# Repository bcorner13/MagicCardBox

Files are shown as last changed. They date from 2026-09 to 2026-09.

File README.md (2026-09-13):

# MagicCardBox

A parametric hinged-lid storage box for Magic: The Gathering cards, modeled in FreeCAD 1.1.

Two printed parts, no fasteners. The lid is a single piece that carries the rear wall and
pivots on hinge tabs engaging sockets in the box side walls, so the whole back of the box
folds open.

| | |
|---|---|
| Outer envelope | 97 × 69 × 67 mm (`Width` × `Depth` × `Height`) |
| Wall | 2.0 mm nominal, 6.0 mm at the hinged side walls |
| Parts | Box tub + lid (with integral rear wall) |
| Target | Creality K2 Plus — PLA for test, ASA for production |

## Layout

```
MagicCardBox.FCStd        box tub, hinge sockets
Lid.FCStd                 lid top plate + rear wall + hinge tabs (2 bodies, 1 Part)
MagicCardAssembly.FCStd   assembly with a solved Revolute joint
Params.FCStd              VarSet — every parametric variable lives here
3mf/  stl/                tracked print deliverables
gcode/                    slicer output (gitignored, regenerable)
images/                   renders and screenshots
macros/                   project .FCMacro files — all model changes go in as macros
scripts/                  audit_parametric.py
```

## Working on this model

Read `CLAUDE.md` first — it documents the assembly architecture and this project's
parametric debt. `plan.md` has the literal-to-Param mapping for the outstanding work.

Inspect and edit the `.FCStd` files through the FreeCAD MCP bridge only; a PreToolUse hook
in `.claude/settings.json` blocks shell access to them.

Before committing any model change:

```bash
python3 scripts/audit_parametric.py
```

Baseline at bootstrap (2026-09-13) is **19 issues** — all unbound dimensional literals in
the hinge geometry. Target is zero.

## Status

Geometry is ~95% complete and recomputes clean; every body is a single valid solid. Not yet
printed. Remaining work is parametric cleanup (see `plan.md`), then a PLA test print to tune
the hinge clearances.

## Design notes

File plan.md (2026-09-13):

# Plan — MagicCardBox

**Status:** geometry was built manually before this project was bootstrapped. This plan
documents the as-built model and the remaining work to bring it into compliance with
`PROJECT_BOOTSTRAP.md` / `CAD_STANDARDS.md`.

Last verified against the live model via the FreeCAD MCP bridge: **2026-09-13**
(FreeCAD 1.1.3, all four documents open and unmodified).

---

## PARAMETERS

Current `Params.FCStd` → `VarSet` contents (verified live, 5 variables):

| Name | Type | Default | Drives |
|---|---|---|---|
| `Width` | `App::PropertyLength` | 97.0 mm | Box X extent; lid X extent; hinge sketch offset (`Width / 2`) |
| `Depth` | `App::PropertyLength` | 69.0 mm | Box Y extent; lid Y extent (`Depth + WallThickness`) |
| `Height` | `App::PropertyLength` | 67.0 mm | `Pad.Length` (box body); `LidPlane` datum Z offset |
| `WallThickness` | `App::PropertyLength` | 2.0 mm | Lid `Pad.Length`, `RearWall` `Pad001.Length`, front/back wall pocket offset |
| `SideWallThickness` | `App::PropertyLength` | 6.0 mm | `Pocket002.Length` (`Width − SideWallThickness * 2`) |

### Parameters that MUST be added (currently literals in the model)

These are the 19 audit violations. Each literal below needs a VarSet variable and an
expression binding — one knob, one concern (global rule #5), and clearances decoupled per
mating interface (global rule #4).

| Proposed Param | Type | Value today | Replaces |
|---|---|---|---|
| `HingeTabRadius` | Length | 10.0 mm | `MagicCardBox/Sketch001.Constraints[0]` (Radius), `Lid/Sketch002.Constraints[1]` (Radius) |
| `HingePinDia` | Length | 6.0 mm | `MagicCardBox/Sketch001.Constraints[12]`, `MagicCardBox/Sketch002.Constraints[3]` (Diameter) |
| `HingePinClearance` | Length | **absent** | new — per-side clearance between lid pin hole and box boss. Today all three Ø6 features are the *same* literal, i.e. a zero-clearance interference fit. `Lid/Sketch003.Constraints[0]` becomes `HingePinDia + HingePinClearance * 2`. |
| `HingeAxisInset` | Length | 5.0 mm | `MagicCardBox/Sketch001.Constraints[1]` and `[15]`, `MagicCardBox/Sketch002.Constraints[0]` and `[1]`, `Lid/Sketch002.Constraints[9]`/`[10]`, `Lid/Sketch003.Constraints[3]`/`[7]` — the hinge-axis offset from the rear/bottom edges |
| `HingeTabThickness` | Length | 5.0 mm | `Lid/Pad002.Length` (HingeTab) |
| `HingeSocketDepth` | Length | 5.0 mm | `MagicCardBox/Pocket.Length` |
| `HingeTabClearance` | Length | **absent** | new — per-side clearance between the lid hinge tab and its socket in the box side wall. `Pocket.Length` becomes `HingeTabThickness + HingeTabClearance`. |
| `EdgeFilletRadius` | Length | 1.0 mm | `Lid/Fillet.Radius` |
| *(reuse `WallThickness`)* | — | 2.0 mm | `MagicCardBox/Sketch003.Constraints[9]` and `[10]`, `MagicCardBox/Pocket001.Length` — **only if** these genuinely express wall thickness. Verify before binding; if they express something else, give them their own Param. |

> `HingeAxisInset` is listed as a single knob because every site currently holds the same
> 5.0 mm value **and** they describe the same physical thing (where the pivot sits relative
> to the rear/bottom corner). Confirm that reading against the geometry before binding —
> "variables that just happen to have the same current value are still different concepts."

---

## FEATURE TREE (as built)

### `Params.FCStd`
- `VarSet` (`App::VarSet`) — 5 variables above. No other objects.

### `MagicCardBox.FCStd` — the box body (27 objects)
1. `Part` (`Box001`, App::Part) — container
2. `Body` (`Box`, PartDesign::Body)
3. `Sketch` on `XY_Plane` — outer footprint rectangle. Bound: `Constraints[9] → Width`, `Constraints[10] → Depth`. Fully constrained.
4. `Pad` — `Length → Height`
5. `Sketch001` (`HingProfile`) on `YZ_Plane`, `AttachmentOffset.Base.z → Width / 2` — hinge socket profile on the side wall. **4 unbound literals.**
6. `Pocket` — hinge socket cut. **`Length = 5.0` unbound.**
7. `Sketch002` on `YZ_Plane`, `AttachmentOffset.Base.z → Width / 2` — hinge pin/boss circle. **3 unbound literals.**
8. `Pocket001` — **`Length = 2.0` unbound.**
9. `Mirrored` — mirrors the hinge features to the opposite side wall
10. `Sketch003` on `YZ_Plane` — interior cavity profile. `Constraints[8] → WallThickness`; **`[9]` and `[10]` unbound.**
11. `Pocket002` — `Length → Width − SideWallThickness * 2` (hollows the interior)

### `Lid.FCStd` — the lid + integral rear wall (42 objects)
1. `Part` (`Lid`, App::Part) — container holding both bodies
2. `Body` (`Lid001`) — the top plate
   - `DatumPlane` (`LidPlane`) on `XY_Plane001`, `AttachmentOffset.Base.z → Height`
   - `Sketch` (`LidSketch`) — `Constraints[8] → Width`, `[9] → Depth + WallThickness`, `[10] → Depth / 2`. Fully constrained.
   - `Pad` — `Length → WallThickness`
3. `Body001` (`LidBack`) — the rear wall that swings with the lid
   - `Sketch001`, `AttachmentOffset.Base.z → -Depth`; `Constraints[8] → Width`, `[9] → Height`
   - `Pad001` (`RearWall`) — `Length → WallThickness`
   - `Fillet` — **`Radius = 1.0` unbound**
   - `DatumPlane001` — ⚠️ attached to `Fillet.Face6` (**feature face — DAG risk, global rule #3**)
   - `Sketch002` on `DatumPlane001` — hinge tab profile. **3 unbound literals.**
   - `Binder001`, `Binder002` (SubShapeBinder)
   - `Pad002` (`HingeTab`) — **`Length = 5.0` unbound**
   - `DatumPlane002` — ⚠️ attached to `Pad` object, MapMode `ObjectYZ` (feature reference)
   - `Sketch003` on `DatumPlane002`, `AttachmentOffset.Base.z → Width / 2 − WallThickness` — hinge pin hole. **3 unbound literals.**
   - `Pocket`, `Mirrored` — pin hole, mirrored to the other side

### `MagicCardAssembly.FCStd` — fit check (14 objects)
- `Assembly` (`Assembly::AssemblyObject`)
- `Box001` (`App::Link` → `MagicCardBox#Part`) — grounded
- `Lid` (`App::Link` → `Lid#Part`)
- `GroundedJoint` on the box; `Joint` (`Revolute`) between `LidBack.Face13` and `Box.Face21`, axis along X at (46.5, 29.5, 5) in link-local coordinates
- Audit: **clean** (no unbound dims — assembly carries no design dimensions of its own)

---

## CONSTRAINT STRATEGY

- All sketches are already **fully constrained** (verified: `FullyConstrained == True`, DoF 0
  on all 9 sketches across both part documents). The debt is *binding*, not *constraining*.
- Fixes go in as `macros/*.FCMacro` files that: (a) `addProperty` the missing VarSet
  variables if absent, then (b) `setExpression` on the named constraint indices. Idempotent —
  skip properties that already exist, overwrite expressions rather than append.
- Never touch `LineSegment StartX/EndY` or `Circle CenterX/CenterY` to move geometry.
- Retarget `DatumPlane001` off `Fillet.Face6` onto a `PartDesign::Plane` offset from a
  principal plane, then reattach `Sketch002` to it. Same for `DatumPlane002`. This is the
  one change that may shift geometry — do it before the parametric binding pass, verify the
  recompute is clean, and re-check the assembly joint still solves.

---

## VALIDATION

1. `python3 scripts/audit_parametric.py` → must report `0 issues`.
2. Sweep test: set `Width` 97 → 110, `Depth` 69 → 80, `Height` 67 → 75 in `Params.FCStd`,
   recompute all three dependent docs, confirm no errors and no touched objects. Restore.
3. `validate_document` on each doc → all objects healthy.
4. Assembly interference check: `Shape.common()` between lid hinge tab and box socket must
   be > 0 only by the intended clearance, and the closed lid must not intersect the box.
5. Export STL → check manifold, then slice for the K2 Plus and record cost.

---

## REMAINING WORK (ordered)

1. ~~Retarget `DatumPlane001` / `DatumPlane002` off feature references onto datum planes.~~ **Still open** — see "Parameter sweep" below; the scope is now wider than these two datums.
2. ~~Add the missing Params (table above), including the two **absent** clearance knobs.~~ **Done 2026-09-13** — 10 variables added via `macros/01-bind_params.FCMacro`.
3. ~~Bind all 19 unbound dimensions via macro.~~ **Done 2026-09-13** — 19/19 bound, geometry verified bit-identical.
4. ~~Re-run the audit until clean~~ **Done — 0 issues.** Parameter sweep test **FAILED** — see below.
5. Fix the sweep defects (D1–D5 below).
6. Set `HingePinClearance` / `HingeTabClearance` to real values before printing.
7. Export `stl/` + `3mf/`, slice, confirm the $36–$45 target.
8. Test print in PLA; fill in the print profile table in `CLAUDE.md`.

---

## Parameter sweep — result: FAILED (2026-09-13)

Validation step 2 was run after the binding pass. The bindings themselves are correct —
every literal now tracks its Param — but the model **does not survive a parameter change**.
These are pre-existing modeling defects, independent of the 19 bindings, uncovered *because*
the model became parametric enough to sweep. Measured one parameter at a time from a freshly
reloaded document:

| # | Change | Symptom | Root cause |
|---|---|---|---|
| **D1** ✅ **FIXED** | `Depth` 69 → 80 | `MagicCardBox/Sketch003` goes **Invalid**, so `Pocket002` cannot rebuild and the box body silently keeps its old shape (vol stays 87462, Y stays ±34.5) | **External-geometry index shift** — measured, not inferred. `Sketch003` is correctly *attached* to `YZ_Plane`, but it dimensions against projected edges of `Mirrored` Face3. At `Depth` 80 that face gains two bounding edges (the hinge cut-out stops coinciding with the rear face and becomes an interior notch), so every external GeoId shifts by two: the top edge moves `-7`→`-9`, the left edge `-8`→`-10`, while the constraints still reference `-7`/`-8`. **Not** a cross-document problem and **not** an attachment problem — a third mechanism that datum/binder discipline does not cover. |
| **D1b** ✅ **FIXED** | `Depth`, any | `MagicCardBox/Sketch001` and `Sketch002` dimension against projected external geometry too — and fail **silently**, which is worse. After a sweep-and-restore, Sketch002's projected edge `-3` was left **stale** at `(42.50,0)→(42.50,75.00)` (values from the sweep, not the restored model) and its distance resolved on the opposite side: the pin centre moved from local x 29.5 to 47.5, outside the box. `Pocket001` then cut nothing, pins stayed full length, body came back 113.10 mm³ heavy (= 2 × the Ø6×2 trim that never happened). DoF stayed 0, state stayed "Up-to-date", nothing flagged. | Both sketches have an **empty `ExternalGeometry` property but a populated `ExternalGeo` projection list** — orphaned cached projections with no live link to refresh from. |
| **D2** ✅ **FIXED** | `Width` 97 → 110 | `Lid/Body001` (LidBack) spans X −48.5…61.5 instead of ±55 — grows off-centre, breaking the "centered at (0,0,0)" rule in `CAD_STANDARDS.md` | `Lid/Sketch001` pins one corner with a Coincident to element −5 instead of a Symmetric constraint about the vertical axis. |
| **D3** ✅ **FIXED** | `Height` 67 → 75 | `Lid/Body001` spans Z −8…67 instead of 0…75 — the rear wall hangs below the floor and stops short of the lid | `Lid/Sketch001` is anchored at its **top** edge, so added height grows downward. Its Z anchor is not tied to the box floor. |
| **D4** | any of the three | `MagicCardAssembly/Joint` (Revolute) goes **Invalid** | The joint references named faces `Body001.Face13` / `Body.Face21`. Already flagged as a risk in `CLAUDE.md`; now confirmed. |
| **D5** | after D1 fires | Restoring 97/69/67 does **not** restore the geometry — `MagicCardBox/Body` comes back 87571.81 mm³ vs the correct 87461.94 (+109.87). Reproducible. | A failed recompute leaves a stale tip. **Recovery: close all four documents without saving and reopen from disk.** Do not try to fix this forward. |

| **D6** ✅ **FIXED** | `Depth` 69 → 80 | The lid's **rear wall does not move with Depth**. Box rear goes to Y=40 while the rear wall stays at Y 19.52…36.50 — floating inside the box, detached from the hinge. The lid *top plate* tracks correctly (overhang stays 2.00). | `Lid/Sketch001` has **`AttachmentSupport = []`** — no attachment at all. Its `.AttachmentOffset.Base.z = -Depth` expression is bound but **completely inert**, because with no support the attachment engine never applies the offset. The real position is a hard-coded `Placement` of Y = 34.5, correct only at Depth 69. Invisible to the audit, which does not check Placements — a bound-but-inert expression looks like compliance. |

| **D7** ✅ **FIXED 2026-09-13** | opening the lid at all | The lid **cannot rotate**, footer or no footer. Two pre-existing collisions with the box, both present before the footer existed: (a) the rear panel's inner face vs the box **rear wall and floor** — starts at 5°, peaks at 372.7 mm³ at 45°, spanning X −43.5…43.5 (i.e. *between* the hinge tabs), Y 31.6…34.5, Z 0…2.9; (b) the top plate's underside vs the box **rear top rim**, 22 mm³ at 5°, Z 66.8…67. Total relief needed over 0–90° = **487.7 mm³**. | The hinge axis sits **5 mm inside the rear face and 5 mm above the floor**, so the rear panel's inner face is only 5 mm from the axis and sweeps a cylinder spanning Y 24.5…34.5 — straight through the rear wall. That cylinder is **tangent to the rear outer face**, so any relief large enough to clear the panel removes the 2 mm rear wall entirely at axis height. The assembly's Revolute joint rotates happily because assembly joints do no collision detection. |

---

## Footer hinge relief — done (2026-09-13)

`macros/04-footer_hinge_relief.FCMacro`. The measurement drove the shape: interference
with the footer starts at **5°** of opening and the required relief is **full width**
(X −49.95…49.95, Y 22.77…35.95, Z −2…0, 2249 mm³) — not two hinge-local notches, because
the lid's rear panel spans the whole box width. Split of the swept volume: left tab
197 mm³, centre 1855 mm³, right tab 197 mm³.

Implemented as one full-width slot across the rear of the footer, front edge at
`Depth/2 − HingeAxisFromRear − HingeTabRadius − HingeSwingClearance` = 19.0 mm. That bound
is the forward-most reach of the tab's swept circle, so it stays correct for any
Depth/hinge combination — deliberately ~3.8 mm more generous than the measured 22.77.
Box now rests on the front ~54 mm of the footer plate; the rear ~15 mm is recessed.

Also bound here, both invisible to the audit: `Pad001.Length` (was on `WallThickness` —
different concern, now `FooterHeight`) and `Pad001.TaperAngle` (was the literal 35.999999;
the audit checks Length/Radius but **not TaperAngle**, so it passed while unbound).

New Params: `FooterHeight` 2.0, `FooterTaperAngle` 36°, `HingeSwingClearance` 0.5.

**Superseded the same day by `macros/06-footer_arc_relief.FCMacro`** — see below. Run 04
first (it creates the Params and the pad bindings), then 06.

### 06 — arc relief, replacing the straight slot

The straight slot's front edge at 19.0 mm was the forward reach of the tab's
`HingeTabRadius` circle *at axis height*. Within the 0–90° swing the tab never goes there
— its far corner sweeps **rearward**, not forward — so the true forward limit is set by the
rear panel's outer-bottom corner:

```
R_swing = sqrt((HingeAxisFromRear + WallThickness)² + HingeAxisFromBottom²)
        = sqrt(7² + 5²) = 8.6023 mm
```

The swept envelope's forward boundary is a **cylinder about the hinge axis**, so the cut
face should be that cylinder, not a plane. Sketch006 on `YZ_Plane`: arc of radius
`R_swing + HingeSwingClearance` centred on the axis, closed by lines out to `Depth` and
along `Z = 0` / `Z = -FooterHeight`, pocketed ThroughAll + Midplane.

| | straight slot (04) | arc (06) |
|---|---|---|
| footer edge at Z=0 | 19.00 | 21.89 |
| footer edge at Z=−2 | 19.00 | 23.68 |
| gap to open lid at Z=0 | 5.50 mm | 2.59 mm |
| gap to open lid at Z=−2 | 5.50 mm | **0.83 mm** |
| footer volume | 98140.19 | 98869.38 (+729.19 mm³) |

At zero clearance the arc reaches **Y = 24.500 at Z = −FooterHeight — exactly where the
opened lid's rear-panel edge lands**, so the footer would meet the open lid flush along the
bottom. The residual 0.83 mm *is* `HingeSwingClearance`, and it is also what keeps the two
faces from fusing in a print-in-place part. It cannot be closed further without the lid
binding; closing it properly means rounding the lid panel's end into a knuckle matching the
arc, which is a lid change (see D7).

Verified: zero footer interference across 0–115°, body a single valid closed solid,
smallest face 5.27 mm² (no slivers), no material anywhere rearward of the arc.

**What remains is D7** — a hinge-geometry problem, not a footer problem.

---

## Depth safety — current state (2026-09-13)

**The box is Depth-safe. The lid is not.**

`macros/02-fix_depth_safety.FCMacro` removed every projected-external-geometry dependency
from all three `MagicCardBox` sketches and re-dimensioned them from Params against each
sketch's own origin axes. All three now have `OutList = [Origin, VarSet]` — nothing else.
Verified geometry-neutral at nominal (14/14 shapes identical on volume, area, bbox) and
swept `Depth` = 55 / 69 / 80 / 100:

| | Depth 55 | Depth 69 | Depth 80 | Depth 100 |
|---|---|---|---|---|
| walls front / rear | 2.00 / 2.00 | 2.00 / 2.00 | 2.00 / 2.00 | 2.00 / 2.00 |
| floor | 2.00 | 2.00 | 2.00 | 2.00 |
| pin inset from rear | 5.00 | 5.00 | 5.00 | 5.00 |
| pin trim cut | 56.549 mm³ | 56.549 mm³ | 56.549 mm³ | 56.549 mm³ |
| body valid closed solid | yes | yes | yes | yes |

Restoring to 69 returns **exactly** 87461.942 mm³ — the D5 non-idempotency is gone for
Depth, because it was a consequence of D1/D1b rather than a separate fault.

**D6 still blocks a real Depth change.** The fix is diagnosed and written up in
`macros/03-fix_rearwall_depth_tracking.FCMacro`, which is deliberately **not applied and
not symlinked**. Applied alone it lands Sketch001 on the right placement to 1e-9 mm and
rebuilds Pad001/Fillet/Pad002/Mirrored to exact baseline volumes — but `Lid/Pocket` goes
Invalid, because `DatumPlane002` uses `MapMode ObjectYZ` on `Pad002` and therefore follows
Pad002's **Placement**, which was (0, 34.5, 0) only as a side effect of the very literal
being removed. The pin hole lands at global Y = −5.0 instead of +29.5.

So the rear wall's position and the hinge-tab datum chain are coupled through Placement
inheritance. Making the lid Depth-safe requires re-anchoring `DatumPlane002`,
`DatumPlane001` (which references `Fillet.Face6` — and `Fillet` belongs to the *other*
body, the lid top plate) and `Binder002`, then applying macro 03. That is a lid hinge-chain
restructure and needs its own approved plan.

**Until then:** changing `Depth` gives you a correct box with a rear wall in the wrong
place. `Width` and `Height` remain unsafe for the separate reasons D2/D3.

---

## D7 fixed — knuckle hinge (2026-09-13)

`macros/07-hinge_knuckle_box` + `08-hinge_knuckle_lid` + `10-rim_relief`.

**Why the old hinge could never rotate.** The tab/recess was a SECTOR (an R10 arc closed by
straight edges). A sector is not a surface of revolution, so rotating it sweeps outside its
own outline and digs into the box. A full disc in a disc socket rotates with zero
interference at any angle — that is the whole fix.

**Two constraints, both measured, both forced:**

1. `HingeTabRadius` had to come DOWN from 10 to 5. The largest full knuckle that fits inside
   the side wall is `min(Depth/2 - HingeAxisFromRear, HingeAxisFromBottom)` = 5 mm. The old
   10 mm is exactly why the sector burst out of the side wall.
2. The lid's rear panel cannot reach the bottom. Sweeping the real panel against the real
   box, interference only stops once the panel starts at Z = 10:

   | panel bottom | Z=0 | Z=5 | Z=8 | **Z=10** | Z=12 |
   |---|---|---|---|---|---|
   | interference | 372.73 | 291.36 | 69.01 | **21.99** | 21.99 mm³ |

   It flattens at 10 (the residual is the separate rim nick). That matches the derivation
   `panel bottom >= HingeAxisFromBottom + HingeAxisFromRear`. `PanelBottomZ` is therefore
   BOUND, not free — it is now tied to the top of the socket circle
   (`HingeAxisFromBottom + HingeTabRadius + HingeTabClearance` = 10.4), which satisfies the
   law and makes the neck slot close exactly on the arc.

**Result: zero interference across 0–95°**, from 372.73 mm³. All three solids valid, closed,
single. Every print-in-place gap is **0.4 mm**, one full nozzle width, verified from the
solids and not just the Params:

| interface | box | lid | gap |
|---|---|---|---|
| pin / hole | r 3.000 | r 3.400 | 0.400 radial |
| tab / socket | r 5.400 | r 5.000 | 0.400 radial |
| tab thickness / socket depth | 5.4 deep | 5.0 thick | 0.400 axial |

### Three traps hit while building this — all encoded in the macro headers

* **PartDesign will not reorder features.** The neck must pad BEFORE the disc (the disc
  alone does not touch the raised panel and pads as a disconnected solid). All three routes
  out — `Body.insertObject`, reassigning `Pad.Profile` to a later sketch, and rebuilding the
  tail around a swapped `Tip` — fail with "The graph must be a DAG". The fix was to put both
  shapes in ONE closed outline.
* **`newObject` did not advance the Body tip** for the Mirrored created with empty
  `Originals`, so the mirrored slot silently stayed out of the solid chain and only the +X
  side was cut. `Body.Tip` must be set explicitly.
* **The neck slot was eating half the pin.** A straight inner edge at the axis cut clean
  through it — measured, the pin's end face came back a half-disc (area 14.137 =
  π·3²/2) with its centroid pulled off-axis to Y 28.23. The slot's inner boundary must be
  the socket ARC, which leaves everything inside 5.4 mm untouched.
* Bonus: `a - b + c` is not `a - (b + c)`. Missing parentheses put the slot floor at +0.4
  instead of −0.4. And pinning an arc endpoint with `DistanceY = centre ± R` is degenerate
  (DoF −2); a Vertical from centre to endpoint is the non-degenerate equivalent.

**Still open:** D2 (`Width` — rear panel grows off-centre) and D3 (`Height`). D6 is now moot
for the panel bottom but `Lid/Sketch001`'s attachment is still empty — see macro 03.

---

## D2 / D3 / D6 fixed + footer resized (2026-09-13)

`macros/11-width_depth_footer` + `12-hinge_tab_stable`.

**D2 and D3 were already gone** — the D7 rebuild replaced `Lid/Sketch001` with
origin-relative constraints, which centres the panel and anchors it in Z. Confirmed by
measurement before touching anything.

**Width** was broken by a fresh defect of mine: `MagicCardBox/Sketch007`'s
`AttachmentOffset` was a copied LITERAL (48.5), because macro 07 did
`sl.AttachmentOffset = FreeCAD.Placement(sk.AttachmentOffset)` — that copies the value, not
the binding. The socket tracked `Width`, the neck slot did not; at Width 115 that buried
46.46 mm³ of the lid's neck in the side wall. Now bound to `Width / 2`.

**D6 (Depth)** — `Lid/Sketch001` has no attachment, so its `.AttachmentOffset` expression is
inert and its position was a hard-coded Placement of Y = 34.5. Macro 03 tried giving it a
real attachment and that cascaded (attaching collapses the Body001 feature placements to
identity, dragging `DatumPlane002` and the pin hole). Binding `.Placement.Base.y` directly
sidesteps the attachment engine — geometry-neutral at nominal, and the panel now tracks Depth.

**Footer over-cut.** The arc relief from macro 06 was sized for the OLD lid, whose panel
reached Z = 0 and swung a corner deep into the footer. After the knuckle rebuild:

| | required | cut before | over-cut |
|---|---|---|---|
| footer relief | **180.93 mm³** | 2466.61 mm³ | **2285.69 mm³** |

The required relief is a plain rectangle — Y 29.500…31.953 at *every* Z in the band — and its
front boundary is exactly the hinge axis. That is not a coincidence: every lid part except
the tab disc sits at Δy ≥ 0 **and** Δz ≥ 0 from the axis, so
`Y(θ) = aY + Δy·cosθ + Δz·sinθ ≥ aY` for the whole sweep; and the disc is a surface of
revolution whose lowest point is `aZ - HingeTabRadius` = 0, so it never enters the band.
Hence a flat cut at the axis, not an arc. The open lid's footprint also starts at exactly
Y 29.500, so footer and open lid meet with a uniform **0.5 mm** gap (`HingeSwingClearance`),
against 0.83–2.59 mm for the arc and 5.50 mm for the original slot.

### A branch-instability bug worth remembering

Macro 08's tab was one closed outline: a 270° arc closed by a neck. Its arc endpoints sat at
the circle's **extrema**, reached by "line is vertical/horizontal" + "endpoint on circle" —
which has **two valid solutions**. It held for W97/115 and D69/85, then flipped at
W85 D55 H55 and **stayed flipped**: the disc collapsed to a quarter and the tab lost the
material around the pin hole. Nothing errored; the sketch stayed DoF 0 and fully
constrained. Pinning the endpoints with `DistanceY = centre ± R` is degenerate (a tangency;
DoF −2).

Fixed in macro 12 by splitting the tab into two unambiguous pads — a plain neck rectangle
(`Pad002`, first, so it bridges to the panel) and a plain circle (`Pad004`, second, fusing
into it). A circle has no branch ambiguity.

**Verified across W 80–130, D 50–100, H 50–95** (9 cases): disc intact, all dimensions
tracking, **swing interference 0.0000 mm³**, every solid valid/closed/single.

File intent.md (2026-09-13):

# Intent — MagicCardBox

## Goal

A parametric hinged-lid storage box for Magic: The Gathering cards. The box holds sleeved
decks; the lid is a single piece that carries the rear wall and pivots on side-wall hinge
bosses so it swings open and back without a separate hinge part or hardware.

## Constraints

- Must follow `CAD_STANDARDS.md` (mm, watertight/manifold, centered at origin, 2.0–3.0 mm
  nominal wall).
- Must follow the parametric rules in `CLAUDE.md` and `~/.claude/CLAUDE.md` — every
  dimension bound to `<<Params>>#VarSet.*`, no literal numbers in constraints.
- **Printed as a single part with the lid open** — a print-in-place hinge, no assembly and
  no hardware. Clearances must be sized so the hinge comes off the plate already free.
- Interior sized to hold sleeved MTG decks (current interior envelope ≈ 97 × 69 × 67 mm
  outer, driven by `Width` / `Depth` / `Height`).
- Target price point $36–$45 per the commercial guardrails in `CAD_STANDARDS.md`.
- One printed part. No fasteners.

## Planned additions (agreed 2026-09-13, not yet modelled)

- Finger slots in the front and back walls so a stack of cards can be lifted out.
- The box bottom extended 2 mm as a separate body, tapering outward to a wider footprint.
- Decoration on the outer faces, last.

## Success criteria

- `python3 scripts/audit_parametric.py` reports zero issues.
- Changing `Width`, `Depth`, or `Height` in `Params.FCStd` rescales the whole assembly
  — body, lid, rear wall, and hinge — without breaking a recompute.
- The lid opens and closes on the printed hinge with no binding and no post-print fitting.

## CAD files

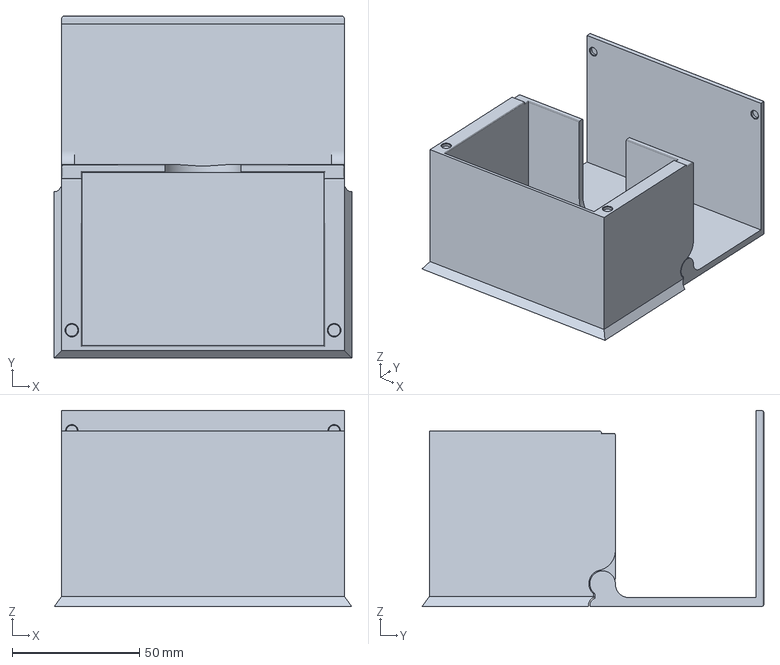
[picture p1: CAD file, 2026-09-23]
3mf/MagicCardBox-100-smooth.3mf
116.8 x 134.3 x 77.0 mm

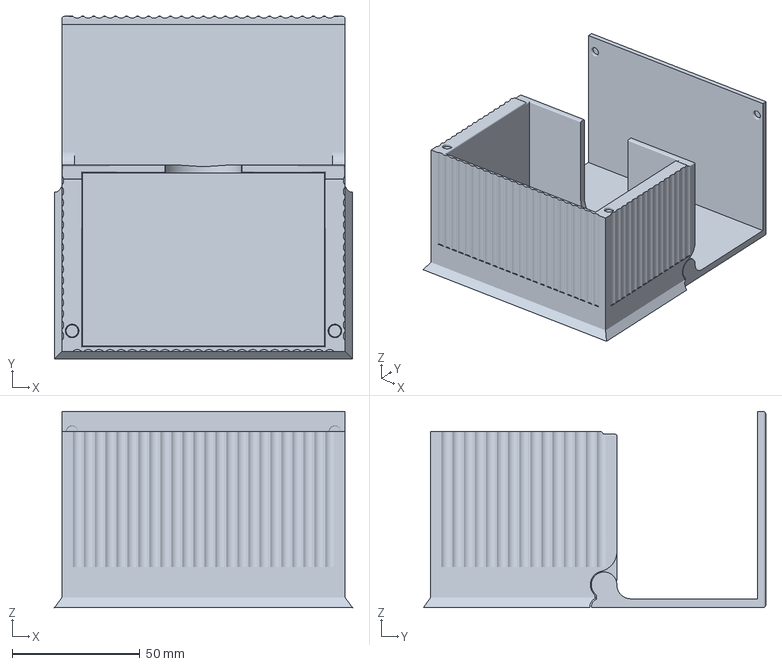
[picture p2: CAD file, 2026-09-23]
3mf/MagicCardBox-100-fluted-label.3mf
116.8 x 134.3 x 77.0 mm

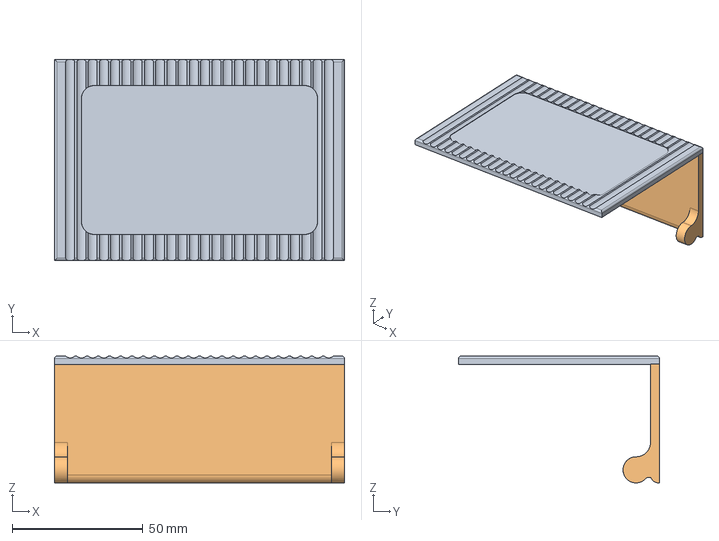
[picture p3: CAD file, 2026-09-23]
Lid.FCStd
111.0 x 77.0 x 48.6 mm
Lid001
LidBack

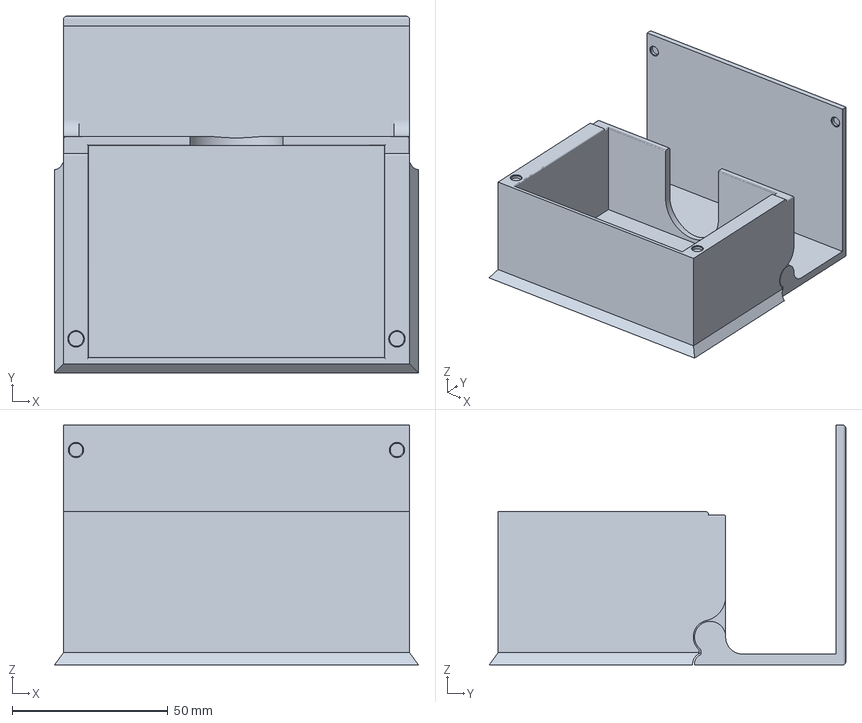
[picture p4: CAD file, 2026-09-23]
3mf/MagicCardBox-60-smooth.3mf
116.8 x 114.5 x 77.0 mm

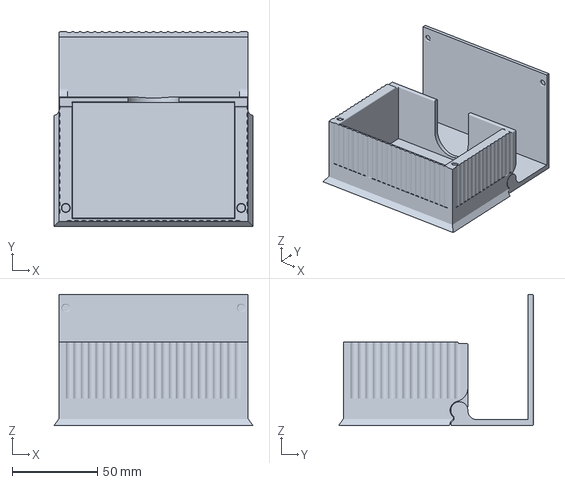
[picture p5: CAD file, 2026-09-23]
3mf/MagicCardBox-60-fluted-label.3mf
116.8 x 114.5 x 77.0 mm

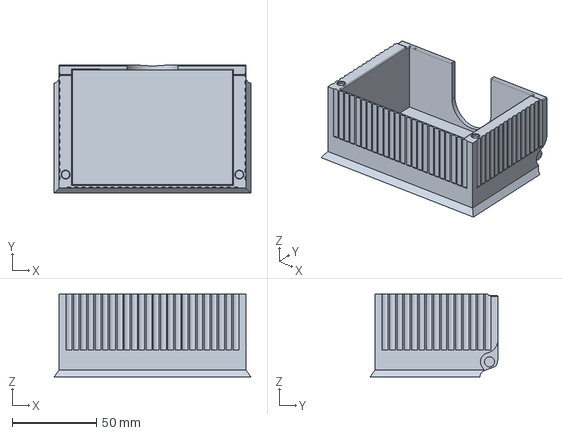
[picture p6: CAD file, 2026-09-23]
MagicCardBox.FCStd
116.8 x 75.9 x 49.2 mm

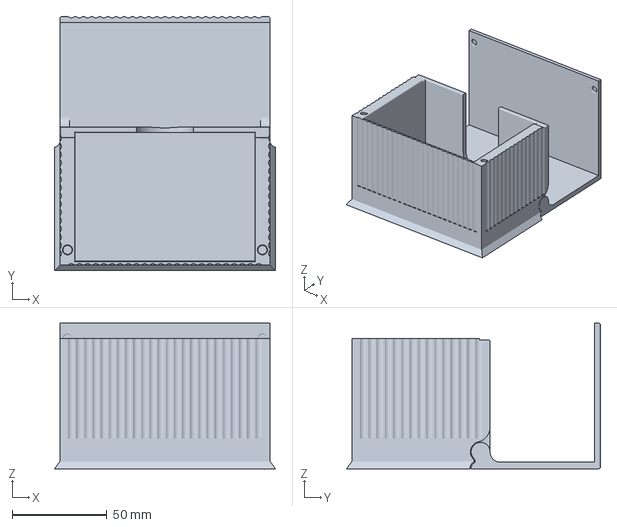
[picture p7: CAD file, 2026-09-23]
3mf/MagicCardBox-100-fluted.3mf
116.8 x 134.3 x 77.0 mm

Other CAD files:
MagicCardAssembly.FCStd
Params.FCStd
3mf/MagicCardBox-60-fluted.3mf
stl/MagicCardBox-100-fluted-label.stl
stl/MagicCardBox-100-fluted.stl
stl/MagicCardBox-100-smooth.stl
stl/MagicCardBox-60-fluted-label.stl
stl/MagicCardBox-60-fluted.stl
stl/MagicCardBox-60-smooth.stl

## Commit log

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2026-09-13 Bind all 19 unbound dimensional literals to Params (audit 19 -> 0)
    Adds macros/01-bind_params.FCMacro: 10 new VarSet variables and 19 expression
    bindings. Geometry-neutral by construction and verified so - every new Param
    defaults to the value its literal already held, and all 14 tracked shapes match
    the pre-change baseline exactly on volume, area, bounding box and centre of mass.
    All three bodies remain valid closed single solids.
    Semantics were established by measuring the solids, not by reading the numbers.
    The key correction: the hinge circle is an INNER wire of the socket profile, so
    the pocket cuts around it leaving a pin standing proud, which a second pocket
    then trims. Pin length is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
    [Lid.FCStd, MagicCardAssembly.FCStd, MagicCardBox.FCStd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]
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2026-09-13 Make the box Depth-safe: remove all projected-external-geometry deps
    macros/02-fix_depth_safety.FCMacro replaces every external-geometry reference in
    all three MagicCardBox sketches with dimensions taken from Params against each
    sketch's own origin axes. All three now have OutList = [Origin, VarSet].
    Scope is wider than the original D1 because fixing Sketch003 alone was not
    enough. Sketch001 and Sketch002 dimension against projected external geometry
    too, and they fail SILENTLY, which is worse than Sketch003 going Invalid:
    After a sweep and restore, Sketch002's projected edge -3 was left stale at
    (42.50,0)->(42.50,75.00) - values from the sweep, not the restored model - and
    the dista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
    [MagicCardBox.FCStd]
2026-09-13 Footer hinge relief + geometry-based repair for the assembly joint
    macros/04-footer_hinge_relief.FCMacro cuts the relief the swept-interference
    measurement actually called for. It is NOT two hinge-local notches: interference
    with the footer starts at 5 degrees of opening and the required relief is full
    width (X -49.95..49.95, Y 22.77..35.95, Z -2..0, 2249 mm3), because the lid's
    rear panel spans the whole box width. Swept volume splits as left tab 197,
    centre 1855, right tab 197 mm3.
    Implemented as one full-width slot across the rear of the footer with its front
    edge at Depth/2 - HingeAxisFromRear - HingeTabRadius - HingeSwingClearance
    = 19.0 mm. That is the forward-most reach of the tab's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
    [MagicCardAssembly.FCStd, MagicCardBox.FCStd, Params.FCStd]
2026-09-13 Arc footer relief; fix a second enum bug in audit_parametric.py
    macros/06-footer_arc_relief.FCMacro supersedes macro 04's straight slot and
    closes the gap between the footer and the opened lid.
    The slot's front edge at 19.0 mm came from the forward reach of the tab's
    HingeTabRadius circle at axis height. Within the 0..90 deg swing the tab never
    goes there - its far corner sweeps rearward, not forward - so the true forward
    limit is the rear panel's outer-bottom corner at
    R_swing = sqrt((HingeAxisFromRear + WallThickness)^2 + HingeAxisFromBottom^2)
    = 8.6023 mm. The slot removed ~5.5 mm of footer for nothing.
    The swept envelope's forward boundary is a cylinder about the hinge axis, so the
    cut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
    [MagicCardAssembly.FCStd, MagicCardBox.FCStd]
2026-09-13 Fix D7: knuckle hinge - lid now rotates with zero interference
    The old tab/recess was a SECTOR (R10 arc closed by straight edges). A sector
    is not a surface of revolution, so rotating it sweeps outside its own outline
    and digs into the box: 372.73 mm3 at 45 deg, starting at 5 deg of opening. A
    full disc in a disc socket rotates freely at any angle - that is the fix.
    Two constraints, both measured and both forced:
    1. HingeTabRadius 10 -> 5. The largest full knuckle that fits inside the side
    wall is min(Depth/2 - HingeAxisFromRear, HingeAxisFromBottom) = 5 mm. The
    old 10 is exactly why the sector burst out of the side wall.
    2. The lid's rear panel cannot reach the bottom. Swept against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
    [Lid.FCStd, MagicCardAssembly.FCStd, MagicCardBox.FCStd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]
2026-09-13 Fix D2/D3/D6, resize the footer, and remove a sketch branch instability
    D2 and D3 were already fixed by the D7 rebuild - replacing Lid/Sketch001 with
    origin-relative constraints centres the panel and anchors it in Z. Confirmed by
    measurement before changing anything.
    Width was broken by a defect introduced in macro 07: Sketch007's AttachmentOffset
    was a copied LITERAL (48.5), because 'sl.AttachmentOffset =
    FreeCAD.Placement(sk.AttachmentOffset)' copies the value, not the binding. The
    socket tracked Width, the neck slot did not, and at Width 115 that left 46.46 mm3
    of the lid's neck buried in the side wall. Now bound to Width / 2.
    D6 (Depth): Lid/Sketch001 has no attachment, so its Attachme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
    [Lid.FCStd, MagicCardAssembly.FCStd, MagicCardBox.FCStd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]
2026-09-13 Replace deprecated Midplane with SideType on all extrude features
    FreeCAD 1.1 deprecates Midplane on FeatureExtrude in favour of SideType:
    "The 'Midplane' property being set for the extrusion of Sketch009 is
    deprecated and has been replaced by the 'SideType' property in
    FeatureExtrude. Please update your script, this property will be removed in
    a future version."
    SideType enum is ["One side", "Two sides", "Symmetric"]; Midplane=True is
    "Symmetric". Macros 06, 10 and 12 now set SideType, and 12 also carries
    SideType rather than Midplane when it rebuilds the pin-hole pocket and the disc
    pad from the previous feature's configuration.
    Pocket006 (the rim relief from Sketch009) was th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
    [MagicCardBox.FCStd]
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2026-09-13 Add finger slots to the front and rear walls
    A U-shaped thumb notch cut down from the rim so a card stack can be pinched out.
    One feature does both walls: the sketch sits on the Body's XZ_Plane and the pocket
    is ThroughAll with SideType Symmetric, so it cuts forward and back from Y=0 -
    through the rear wall, through the already-empty cavity, and through the front
    wall. No mirror needed.
    New Params: FingerSlotWidth 40.0, FingerSlotDepth 25.0 (bottom radius is
    FingerSlotWidth/2). The macro range-checks all three failure modes and refuses
    rather than building a broken profile: the slot must clear the side walls, must
    not invert its straight sides (FingerSlotDepth > FingerSlotWidth/2 -
    WallThic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
    [MagicCardAssembly.FCStd, MagicCardBox.FCStd, Params.FCStd]
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2026-09-13 Export the print-ready 3MF/STL, and fix two defects it uncovered
    Two real defects surfaced while preparing the export, both invisible to every
    check used so far.
    1. The hinge would have FUSED. In the print pose the minimum distance between box
    and lid was 0.0249 mm, not the designed 0.4. Two causes, found by probing:
    - Pad001 (the footer plinth) is padded AFTER the hinge socket is cut, so it
    re-fills the part of the socket below Z=0. The tab disc's lowest point is
    exactly HingeAxisFromBottom - HingeTabRadius = 0, so it sat on the refilled
    footer. Fixed by macro 15: Pocket008 re-cuts the socket at the END of the
    tree, reusing Sketch001 (a later feature may profile a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
    [MagicCardAssembly.FCStd, MagicCardBox-print.3mf, MagicCardBox-print.stl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]
2026-09-13 Add vertical fluting to the box walls (lid top left plain)
    Tighter pitch per Bradley's call: FluteRadius 2.5, FluteDepth 0.7 gives a 3.47 mm
    wide groove on a 4.04 mm front pitch (4.29 side), leaving 0.57 mm flats - reeded
    rather than sparse. Counts 24 front, 15 per side.
    Each flute is a cylinder subtracted from the wall with its centre outside the face
    by FluteRadius - FluteDepth, so the groove bites exactly FluteDepth. CIRCLES, not
    arcs: after the tab's 270 deg arc flipped solver branch at W85 D55 H55 and two arc
    profiles came out at DoF -2, nothing here uses an arc where a circle will do.
    Placement limits, all enforced by the macro rather than assumed:
    - FluteStartZ 12.0 keeps flutes abo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
    [Lid.FCStd, MagicCardAssembly.FCStd, MagicCardBox.FCStd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]
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2026-09-13 Save assembly after joint re-verify
    No geometry change - the joint was re-checked against the fluted model (references
    still resolve, Up-to-date, lid pose unmoved) and the document saved, which rewrites
    the FCStd.
    Environment re-checked at end of session: FreeCAD 1.1.3, MCP addon 0 commits behind
    origin/main. inspect_object on shape-bearing objects and get_sketch_info are still
    broken ('Sketcher.SketchObject' object has no attribute 'ExternalGeometryCount'), so
    the global rule #8 workaround still applies.
    Claude-Session: https://claude.ai/code/session_018sFbcRtuSDQSnDdXVF1zHX
    [MagicCardAssembly.FCStd]
2026-09-13 Fix the hinge after the failed first print, add magnets, export both variants
    The first PLA print snapped at the hinge and strung badly across the back. Root
    cause measured, not guessed: PanelBottomZ held the lid's rear panel 10.4 mm up, so
    box and lid were joined by two R5 discs -- 4 mm of plastic out of 105.
    Bradley rebuilt the lid (panel down to the hinge axis, then HingeNeckDrop carrying
    the neck 3 mm below it); this commit is the box side plus the parametric work.
    20 hinge wrap. Panel to PanelWrapZ=0, footer relief to the circle's front, and a
    relief that ends the zero-clearance ride: the panel's inner bottom edge and
    HengeFilet's roll were BOTH at r=5.000, so the lid r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
    [Lid.FCStd, MagicCardAssembly.FCStd, MagicCardBox-fluted.3mf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]
2026-09-13 Keep the displayed feature in step with the Tip; regenerate both variants
    Macro 24 moved the box Body's Tip to the flutes but left the visibility flag on
    the old tip (MirroredNeckClip), so the 3D view drew the un-fluted shape -- the box
    rendered smooth while the Tip, the exports and every measurement were correctly
    fluted. Caught by eye, not by any check. Macro 24 now moves visibility with Tip.
    The exports were never wrong: macro 16 reads Body.Shape, which is the Tip, not
    whatever happens to be visible. Confirmed by accounting for the flute volume --
    box 4116.71 mm3 + lid 2938.23 mm3 = 7054.94 against a 7020 mm3 mesh delta.
    Both variants regenerated from the current tree, watertight, non-m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
    [Lid.FCStd, MagicCardAssembly.FCStd, MagicCardBox-fluted.3mf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]
2026-09-13 Replace the external-geometry relief with a bound one; bind the box edge breaks
    Bradley's Sketch013/Pocket010 relieved the panel's inner face in the two knuckle
    bands, which PocketHingeWrap cannot reach (it stops at Width/2 - HingeTabThickness
    so as not to cut the knuckles). Without it the full-width panel rode the box at
    r = 5.000 again and the 90 deg print-pose gap fell 0.4000 -> 0.0000.
    It did that by projecting two faces of PocketHingeWrap as external geometry, which
    is the one construction this project has banned twice: hard rule #3 (attached to a
    feature face) and defect D1 (ExternalGeometry on feature faces). It had zero own
    geometry and zero own constraints, so a renumber would leav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
    [Lid.FCStd, MagicCardAssembly.FCStd, MagicCardBox-fluted.3mf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]
2026-09-13 Fix macro 25: Group order must agree with the BaseFeature chain
    Macro 25 rewired BaseFeature but never rebuilt Group. PartDesign carries both
    orderings, and FreeCAD re-derives BaseFeature from Group order on later
    evaluations -- so it rewrote PocketKnuckleRelief.BaseFeature back to Chamfer from
    Group order while Chamfer already pointed at the pocket. A cycle:
    Chamfer.BaseFeature = PocketKnuckleRelief
    PocketKnuckleRelief.BaseFeature = Chamfer
    The Chamfer then held "?Edge30" and died when Bradley opened it for edit;
    cancelling that dialog deleted it, and Tip fell back to PocketHingeWrap.
    Every geometric check I ran had passed -- valid, closed, single solid, 10.000 mm3
    remove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
    [Lid.FCStd, MagicCardAssembly.FCStd, MagicCardBox-fluted.3mf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]
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2026-09-13 Re-export both variants; the fluted 3MF had been overwritten by a slicer project
    3mf/MagicCardBox-fluted.3mf as committed in 1188303 was not a geometry export at
    all -- it was a Creality Print project file saved back over the same name:
    HEAD 3D/3dmodel.model 1,376 bytes 0 vertices 0 triangles
    <metadata name="Application">Creality_Print V7.2.2.5483 Release</metadata>
    NOW 3D/3dmodel.model 708,294 bytes 4,891 vertices 9,774 triangles
    Creality references its geometry elsewhere in the container, so the model part is
    a metadata stub. Every "both 3MFs current" claim since 1188303 was wrong for that
    file. It went unnoticed because the plain 3MF was untouched and BOTH S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
    [Lid.FCStd, MagicCardAssembly.FCStd, MagicCardBox-fluted.3mf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]
2026-09-14 Macro 16: verify the exported files, and correct which commit broke the 3MF
    CORRECTION to 3f69de7's message. The Creality project file was committed in
    e37a2ac, not 1188303, and I put it there -- `git add -A` swept up Bradley's
    sliced project while it sat on the export's filename. 1188303 was clean. So the
    3MF was wrong for two commits, not three, and by my hand rather than by my
    failing to notice someone else's file:
    1188303 3D/3dmodel.model 708294 bytes 9774 tris my export, fine
    e37a2ac 1376 bytes 0 tris project file swept in
    7bc4fa3 1376 bytes 0 tris inherited
    3f69de7 708294 bytes 9774 tris fixed
    Ma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
    [Lid.FCStd, MagicCardAssembly.FCStd, MagicCardBox.FCStd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]
2026-09-14 Fix the lid not closing: three coincident surfaces, not one
    The third print's hinge held, but the lid would not close. It was three
    separate pairs of surfaces driven to the same place, stacked, each hiding
    the next.
    A. The lid panel's inner face and the box's rear face were both at y = 36.
    PocketPanelRelief (macro 27) sets the panel back over its full width to
    Depth/2 + HingeSwingClearance. It cuts the INNER face only, so the outer
    face stays at 38.0 and the print-pose bed plane is untouched.
    B. PanelBottomZ and the socket bore top were the SAME expression,
    HingeAxisFromBottom + HingeTabRadius + HingeTabClearance, so the lid's
    step packed the bore's radial clearance solid. R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
    [Lid.FCStd, MagicCardAssembly.FCStd, MagicCardBox-fluted.3mf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]
2026-09-14 Finger slot rear only: solid front wall
    Bradley's son's call - the back grip is fine, the front should be solid.
    It also means a knocked-over box cannot shed its cards through the front,
    and the flutes now run across the front face unbroken.
    Pocket007 was ThroughAll + Symmetric, so one feature punched both walls.
    Dropped to One side; the sketch normal already pointed the right way, but
    the macro measures which wall survived rather than trusting that, and flips
    Reversed if it guessed wrong.
    Correcting a wrong note in CLAUDE.md while here: it claimed the rear slot
    "is sealed shut and currently does nothing". That is only true with the lid
    CLOSED. The panel swings with the lid, so at 90 deg o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
    [Lid.FCStd, MagicCardAssembly.FCStd, MagicCardBox-fluted.3mf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]
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2026-09-14 Fix Fillet003 for the shorter rim - the box now sweeps to Height 40
    Diagnosed instead of assumed. At Height 40 Fillet003 failed with
    Invalid edge link: ;#d585:da;:H231,E.Edge24
    and exactly ONE of its eleven references had died. The other ten resolved and
    had tracked the rim down correctly (z 65->40, 64->39), and Edge24 was still
    present at the same index, 95 mm at (0, -34, Height) - the front inner rim.
    So it was a stale element-map entry, not a missing edge and not a geometry
    failure; the fillet would have built if the reference had resolved.
    That edge is the one macro 29 created when it closed the front finger slot
    and merged two 32.5 mm segments into one. The reference it was hande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
    [Lid.FCStd, MagicCardAssembly.FCStd, MagicCardBox.FCStd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]
2026-09-14 Build the 60-card variant: card count is now the driving parameter
    CardStackHeight was a free literal measured off a stack. It is now derived
    from the unit the product is actually sold in:
    CardCount = 100 (integer - the product name)
    CardPitch = 0.62 (mm per sleeved card, in a stack - measured)
    CardStackHeight = CardCount * CardPitch
    At CardCount 100 that is 62.0, identical to the literal, so installing the
    binding moves no geometry - macro 32 asserts the box volume is unchanged
    before it will go on.
    100 cards -> CardStackHeight 62.0, Height 65.0, interior 95 x 68 x 63
    60 cards -> CardStackHeight 37.2, Height 40.2, interior 95 x 68 x 38.2
    The 60-card box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
    [Lid.FCStd, MagicCardAssembly.FCStd, MagicCardBox-100-fluted.3mf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]
2026-09-15 Fix the closed lid sitting 1.1mm proud: a 38:1 lever at the hinge
    The box's sealing rail stops at y=29.7, just 1.29mm from the hinge axis at
    y=31, while the front edge is 67mm away. That is a 38:1 lever, so 29 microns
    of print tolerance - a third of one layer - pushed the front of the closed
    lid up 1.1mm. The CAD was never wrong; at nominal the lid is dead flat,
    plate-to-rim 0.0000. The geometry simply multiplies any tolerance by 38.
    Measured on the part with no magnets installed, so this is plastic on plastic.
    LidSeatClearance 0.15 lifts the PLATE clear of the rail (the lid cannot be
    raised as a whole - the panel is pinned to the hinge axis by its knuckle).
    The lid now seats on the front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
    [Lid.FCStd, MagicCardAssembly.FCStd, MagicCardBox.FCStd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]
2026-09-15 Re-export all four variants with the lid seat fix
    The 38:1 lever fix (2cf8570) changed every published variant, not just the
    two card counts - the thicker rear panel, the 4mm footer and the raised lid
    plate are all in the shared model. Exporting only the sizes being printed
    would have left the two plain files shipping the 1.1mm lid tilt, so all four
    are rebuilt.
    tris volume footprint on Z
    100-plain 2012 188.87cm3 116.81 x 133.26 x 76 0.0
    100-fluted 5636 181.20cm3 116.81 x 133.26 x 76 0.0
    60-plain 2012 142.73cm3 116.81 x 108.46 x 76 0.0
    60-fluted 5636 137.25cm3 116.81 x 108.46 x 76 0.0
    Footprint grew fr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
    [MagicCardBox-100-fluted.3mf, MagicCardBox-100-fluted.stl, MagicCardBox-100-plain.3mf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]
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2026-09-15 Hinge bottom corner: R5 roll -> 45deg chamfer, cut as a pocket
    Print 4 drooped and strung at the bottom-rear hinge corner. The R5 roll is a
    downward-facing surface whose tangent is HORIZONTAL where it meets the bottom
    face - 88.8deg at z=0 and over 45deg for the first 1.7mm. A 45deg chamfer is a
    constant 45deg.
    HengeFilet is NOT an edge break. Measured, it is a radius-5.000 cylinder
    centred exactly on the hinge axis (offset 0.0000, Face9/Face10) and it is the
    journal the lid's panel wraps at a constant 5.5000 through the whole swing.
    PartDesign::Chamfer cannot do this edge. It is 100.2mm long at (0,36,0) and
    crosses regions where the adjacent rear face is too short to land on - the
    finger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
    [Lid.FCStd, MagicCardAssembly.FCStd, MagicCardBox-100-fluted.3mf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]
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2026-09-15 Halve the floating cantilever: clear what was blocking Bradley's fix
    Creality Print warns "object Object_1 has floating cantilever" on every slice.
    Bradley fixed it with two changes of his own; the work here was mostly clearing
    what stopped them reaching the part.
    flat down-facing area at z=0 458.4 -> 176.9 mm2 (-61%)
    footer reach at z=-0.1 26.4 -> 28.381
    panel swing 0.4000 flat, zero interference (unchanged)
    WHAT FIXED IT
    PanelBottomFillet rounds the rear panel's bottom inner edge. Not cosmetic - it
    shrinks the lid's SWEPT ENVELOPE, freeing space the box can then occupy:
    z=-0.5 26.5 -> 29.00 z=-1.0 26.0 -> 27.25 z=-2.0 25.5 -> 26.25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
    [Lid.FCStd, MagicCardAssembly.FCStd, MagicCardBox.FCStd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]
2026-09-15 Re-export all six variants; fix a bbox gate that measured the wrong thing
    facets volume 3mf tris dvol% footprint
    100-smooth 10784 188.70cm3 10784 0.000 116.81 x 133.26 x 76
    100-fluted 26884 180.90cm3 26884 0.001 116.81 x 133.26 x 76
    100-f-label 30044 178.32cm3 30044 0.001 116.81 x 133.26 x 76
    60-smooth 10750 142.55cm3 10750 0.001 116.81 x 108.46 x 76
    60-fluted 26850 137.00cm3 26850 0.001 116.81 x 108.46 x 76
    60-f-label 30010 134.41cm3 30010 0.001 116.81 x 108.46 x 76
    All watertight, manifold, no self-intersections, 2 components, on Z=0,
    print-pose gap 0.4000. Volume accuracy 0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
    [Lid.FCStd, MagicCardAssembly.FCStd, MagicCardBox-100-fluted-label.3mf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]
2026-09-15 Print 5 result: the hinge survived PETG, and the droop is not a material problem
    THE HINGE CAME OFF THE PLATE FREE. PETG in clearances sized for PLA -
    HingeTabClearance 0.4, HingeSwingClearance 0.5, and the 0.5mm gap under the
    cantilever - did not fuse. That was the one failure that cannot be rescued
    after the fact. Recorded as a fact about the joint; it does NOT mean PETG fixed
    anything.
    THE LID SITS FLUSH AT REST and closes better than print 4. That is
    LidSeatClearance 0.15 working: the seat moved off a knife-edge 1.3mm from the
    pivot (38:1 amplification, 1.1mm of front lift) onto the front rim at 66mm
    (1:1).
    CURVED OVERHANGS PRINT, FLAT ONES DROOP. The two knuckle undersides are
    cylindr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
    [MagicCardBox-60-fluted-label.3mf]
2026-09-16 Rounds 8-9: cantilever to zero, and the check that had been lying all session
    Print 6 fixes, plus a 3 mm rear wall that turned out to finish the floating
    cantilever work rather than cost anything.
    CardPitch was two measurements in one knob
    The 60-card box was 5 mm short. Raising the global CardPitch "fixed" it and
    both card counts verified clean -- but it forced the 100 box to Height 73.3,
    where it would hold ~114 cards. Bradley identified why: Ryan's sleeves are
    thicker, and the printed 100 box still has ~2 mm free above its 101st card.
    thin sleeve true 0.6040 CardPitch 0.6200 slack 0.0160 mm/card
    Ryan's true 0.6867 CardPitch 0.7033 slack 0.0163 mm/car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
    [Lid.FCStd, MagicCardAssembly.FCStd, MagicCardBox-100-fluted-label.3mf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]
2026-09-16 Round 10: reshape the ramp spline -- every overhang under 20 deg is gone
    The frame was never the limit; the curve was. Same frame, same wall guard, same
    landing point, same RampMinWall, no dimensional change at all -- only the three
    interior spline poles moved.
    min ramp angle, MEASURED ON THE SOLID 5.38 deg -> 19.88 deg
    geometric ceiling 20.67 deg
    rear wall minimum 1.982 -> 0.853 mm (guard 0.80)
    flat down-facing at z=0 0.0 mm2, unchanged
    panel swing 0.4000 flat, zero interference
    The old third pole sat at z = -0.03, level with the (29, 0) endpoint, so the
    curve ran int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
    [Lid.FCStd, MagicCardAssembly.FCStd, MagicCardBox-100-fluted-label.3mf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]
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2026-09-23 Round 13: the LidBack gusset was being deleted, not clipped
    Fillet002 (added in the GUI for strength, "to follow the curve of the box")
    contributed 0.000000 mm3 to the finished part. Measured:
    gusset added 17.1681 mm3 bbox y 32.5..36.5, z 10..14
    surviving in tip 0.000000 mm3 -> 0.0000 %
    PocketPanelRelief is a full-width ThroughAll cut of y [26.5, 37] x z [10,
    48.553], which wholly contains it. The coincidence trap in a fifth form: the
    fillet was taken on the panel face at y = Depth/2, and the relief then MOVES
    that face to y = Depth/2 + HingeSwingClearance, taking the blend with it.
    Nothing complained -- valid, bound, Up-to-date, audit clean.
    Fix: PanelNeckGusset, a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
    [Lid.FCStd, MagicCardAssembly.FCStd, MagicCardBox-100-fluted-label.3mf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]
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
